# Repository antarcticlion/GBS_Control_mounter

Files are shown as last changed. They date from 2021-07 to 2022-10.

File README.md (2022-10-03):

# GBS_Control_mounter
[GBS-Control](https://github.com/ramapcsx2/gbs-control) Mounting plate for GBS-8200/8220

これはテスト中のプロダクトです。不具合が残っているかもしれません。  

----
# Note for Rev 0.6
外形を調整、クロックジェネレータモジュールを追加。
  
外形  
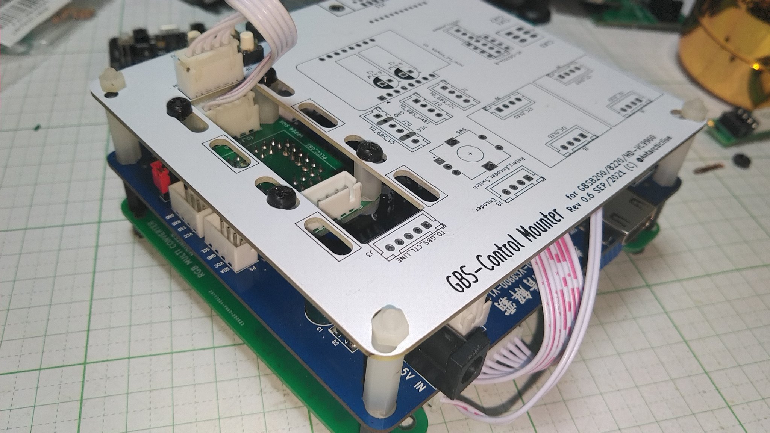
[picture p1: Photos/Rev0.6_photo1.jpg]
Rev06 photo 1
  
  
RGB MULTICONV と一緒にスタックした例  
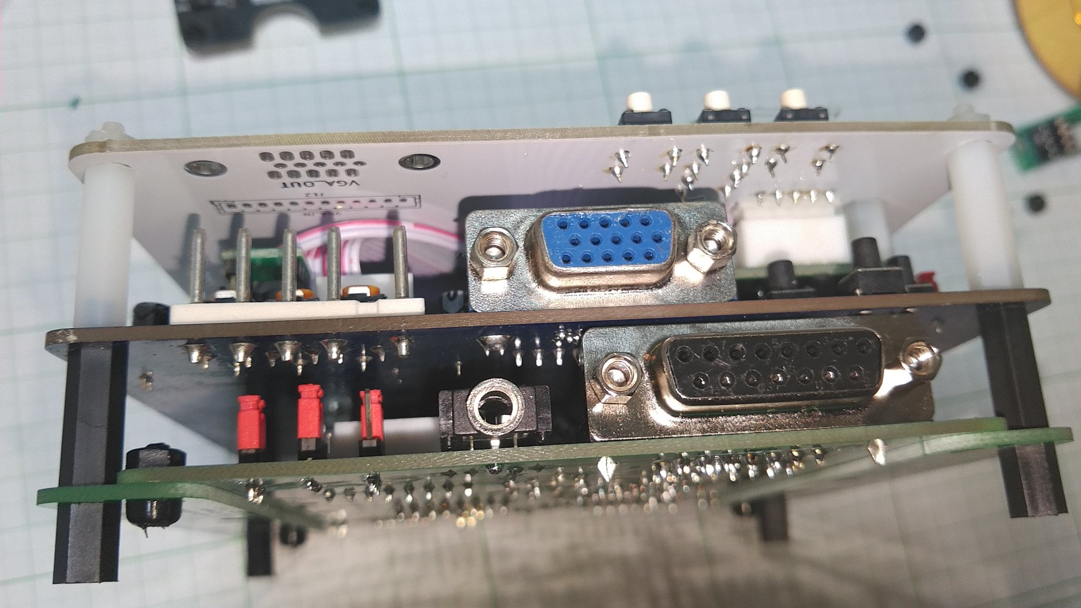
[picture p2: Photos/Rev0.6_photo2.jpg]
Rev06 photo 2
  

クロックジェネレータモジュール(秋月電子通商 AE-Si5351A-Bを使用)
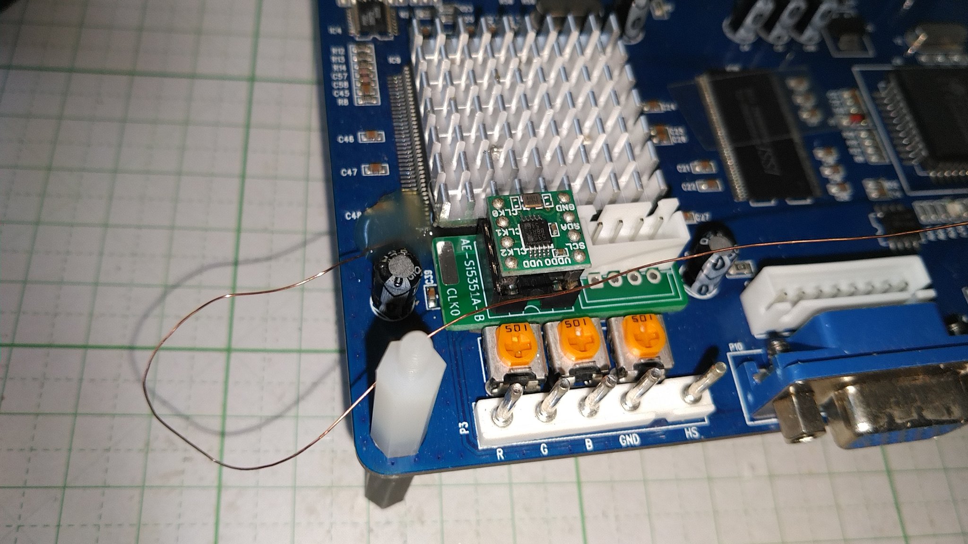
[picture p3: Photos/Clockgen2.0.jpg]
Rev06 photo 3
  

# Note for Rev 0.4
HD-VC9900をサポート

# Note for Rev 0.3
This is a product under test. There may be some bugs left.  
これはテスト中のプロダクトです。不具合が残っているかもしれません。  

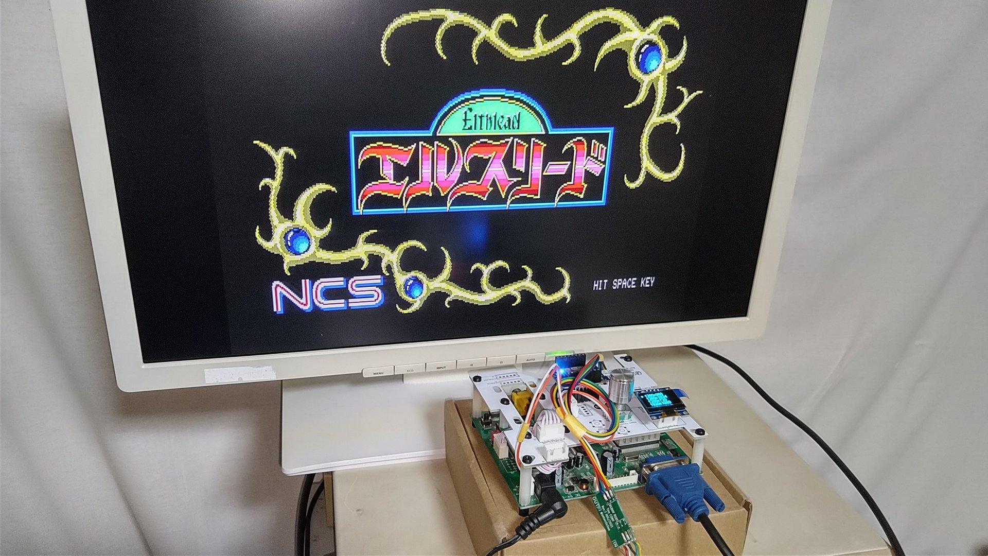
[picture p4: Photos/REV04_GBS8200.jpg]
Rev04 photo 1
  
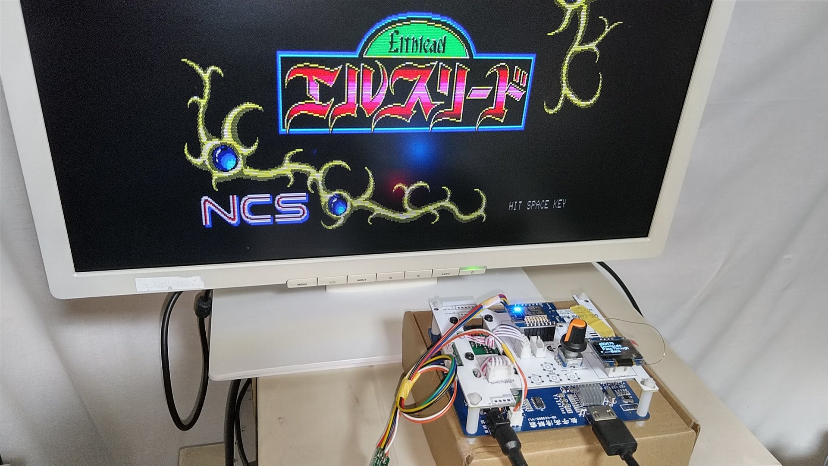
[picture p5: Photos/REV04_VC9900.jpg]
Rev04 photo 2
  
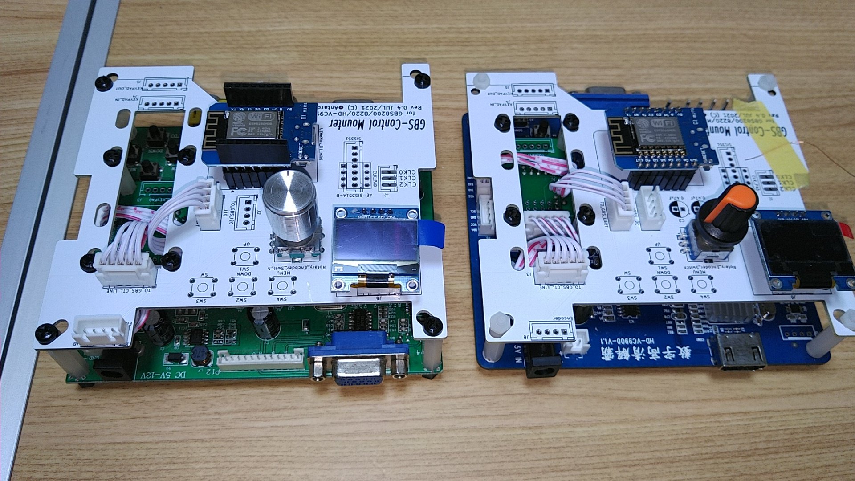
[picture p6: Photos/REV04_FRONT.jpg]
Rev04 photo 1
  
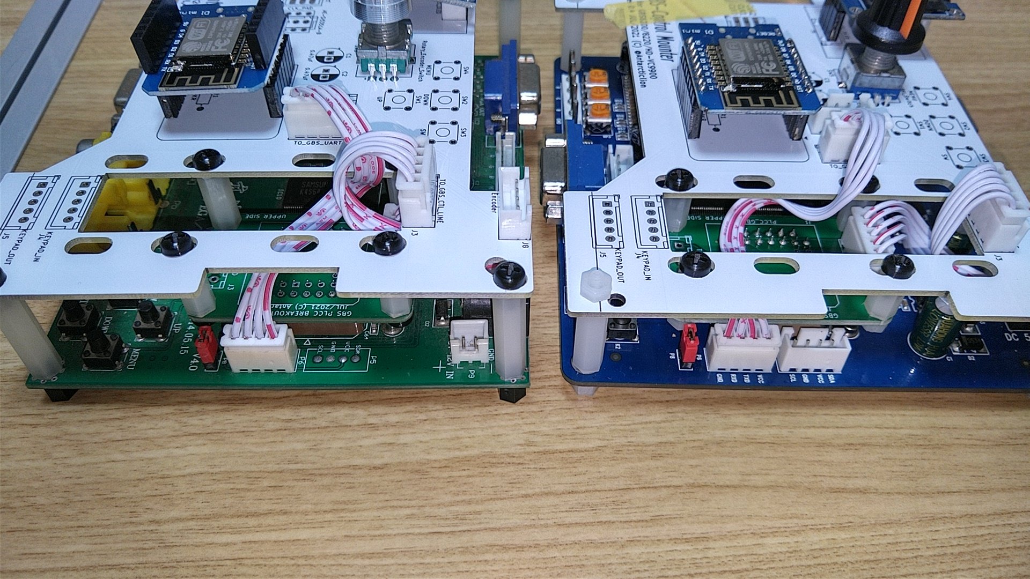
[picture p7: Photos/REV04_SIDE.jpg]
Rev04 photo 2
  
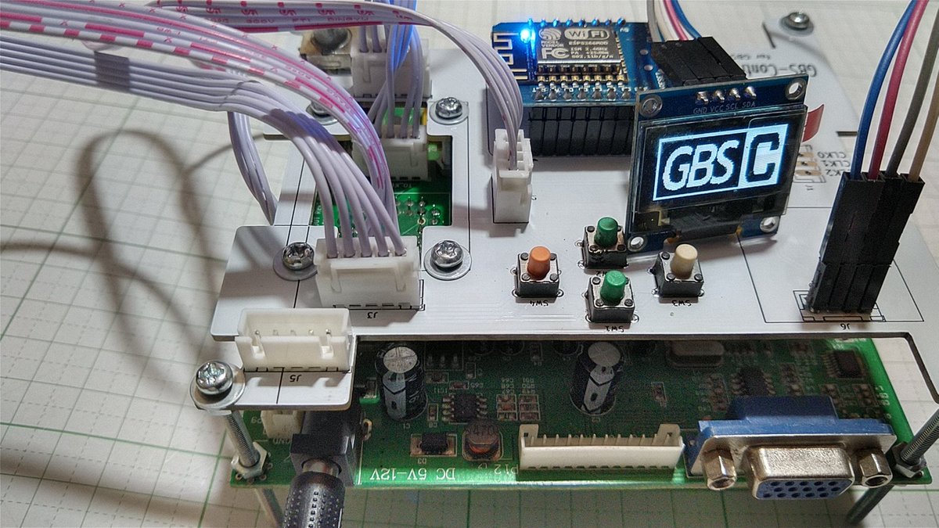
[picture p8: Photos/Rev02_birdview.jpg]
Rev02 photo 1
  
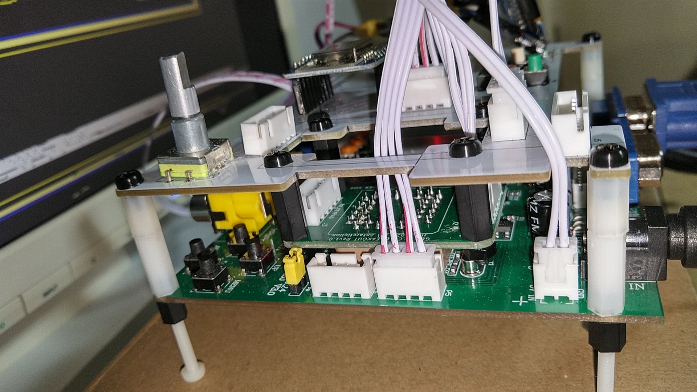
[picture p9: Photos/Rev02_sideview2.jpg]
Rev02 photo 2
  
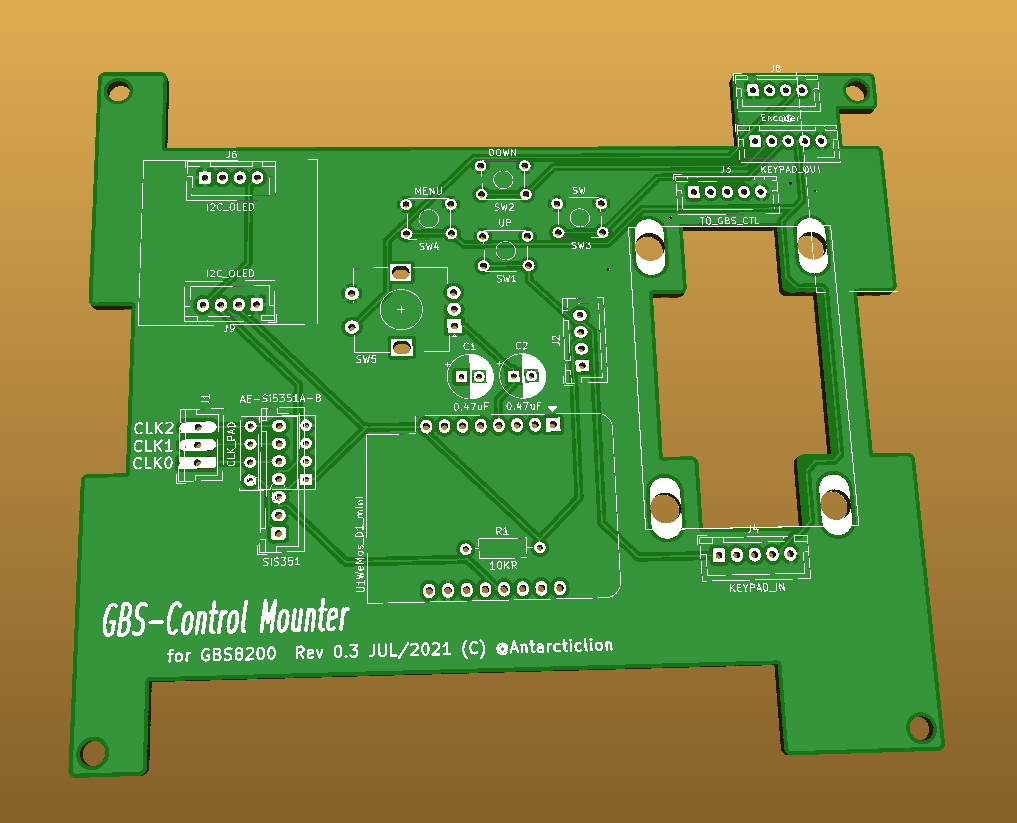
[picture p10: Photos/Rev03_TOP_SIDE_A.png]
Rev03 board 1
  
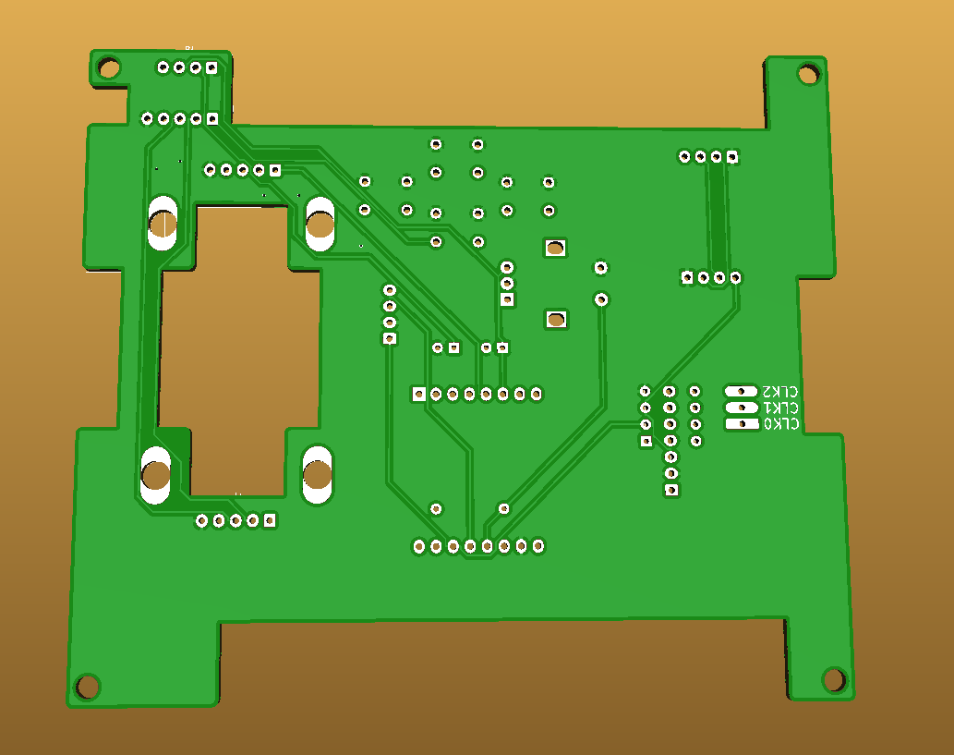
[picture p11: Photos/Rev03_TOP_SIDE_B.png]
  
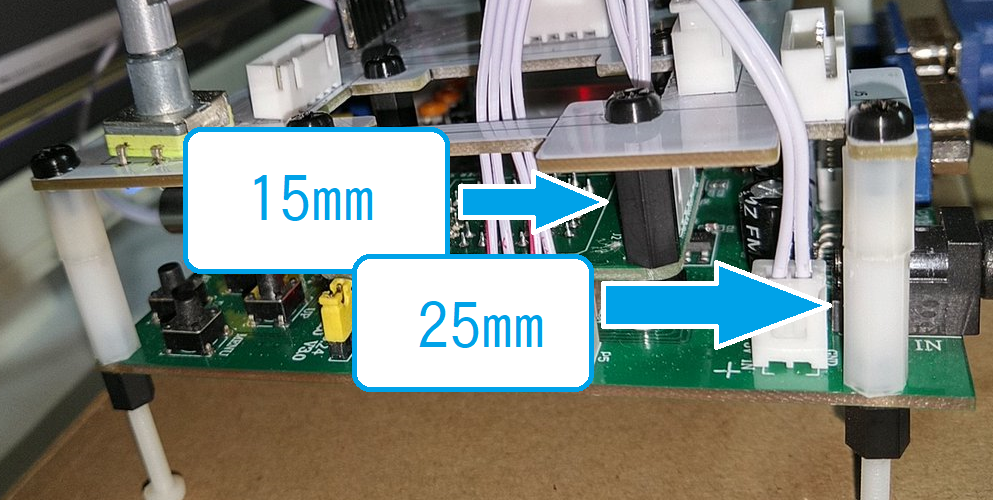
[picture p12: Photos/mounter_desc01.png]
  

# ライセンス

CC BY-SA 4.0とMITライセンスのデュアルライセンスとします。

クリエイティブコモンズ　表示 - 継承 4.0 国際 (CC BY-SA 4.0)

https://creativecommons.org/licenses/by-sa/4.0/  
https://creativecommons.org/licenses/by-sa/4.0/legalcode

Copyright 2019-2020 @antarcticlion

Permission is hereby granted, free of charge, to any person obtaining a copy of this software and associated documentation files (the "Software"), to deal in the Software without restriction, including without limitation the rights to use, copy, modify, merge, publish, distribute, sublicense, and/or sell copies of the Software, and to permit persons to whom the Software is furnished to do so, subject to the following conditions:

The above copyright notice and this permission notice shall be included in all copies or substantial portions of the Software.

THE SOFTWARE IS PROVIDED "AS IS", WITHOUT WARRANTY OF ANY KIND, EXPRESS OR IMPLIED, INCLUDING BUT NOT LIMITED TO THE WARRANTIES OF MERCHANTABILITY, FITNESS FOR A PARTICULAR PURPOSE AND NONINFRINGEMENT. IN NO EVENT SHALL THE AUTHORS OR COPYRIGHT HOLDERS BE LIABLE FOR ANY CLAIM, DAMAGES OR OTHER LIABILITY, WHETHER IN AN ACTION OF CONTRACT, TORT OR OTHERWISE, ARISING FROM, OUT OF OR IN CONNECTION WITH THE SOFTWARE OR THE USE OR OTHER DEALINGS IN THE SOFTWARE.

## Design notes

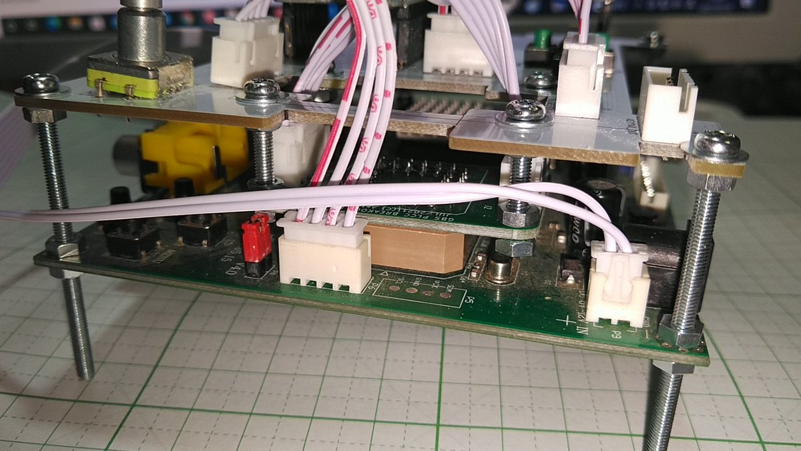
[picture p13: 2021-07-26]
Photos/Rev02_sideview.jpg

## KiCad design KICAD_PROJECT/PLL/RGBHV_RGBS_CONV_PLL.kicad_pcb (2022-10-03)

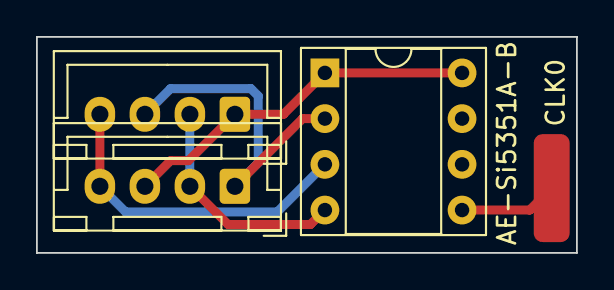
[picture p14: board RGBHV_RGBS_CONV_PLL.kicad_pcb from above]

Board: 2 copper layers, 30.0 x 12.0 mm, 4 parts (0 on the bottom side), 5 nets.

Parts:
J1: I2C OVERLAY; JST_XH_B4B-XH-A_1x04_P2.50mm_Vertical
J4: CLK0; PAD
J5: I2C GBS; JST_XH_B4B-XH-A_1x04_P2.50mm_Vertical
U1: AE-Si5351A-B; DIP-8_W7.62mm_Socket

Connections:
unnamed: J1.1, J5.3, U1.1, U1.8
unnamed: J1.2, J5.2, U1.4
unnamed: J1.3, J5.1, U1.2
unnamed: J1.4, J5.4, U1.3
unnamed: J4.1, U1.5

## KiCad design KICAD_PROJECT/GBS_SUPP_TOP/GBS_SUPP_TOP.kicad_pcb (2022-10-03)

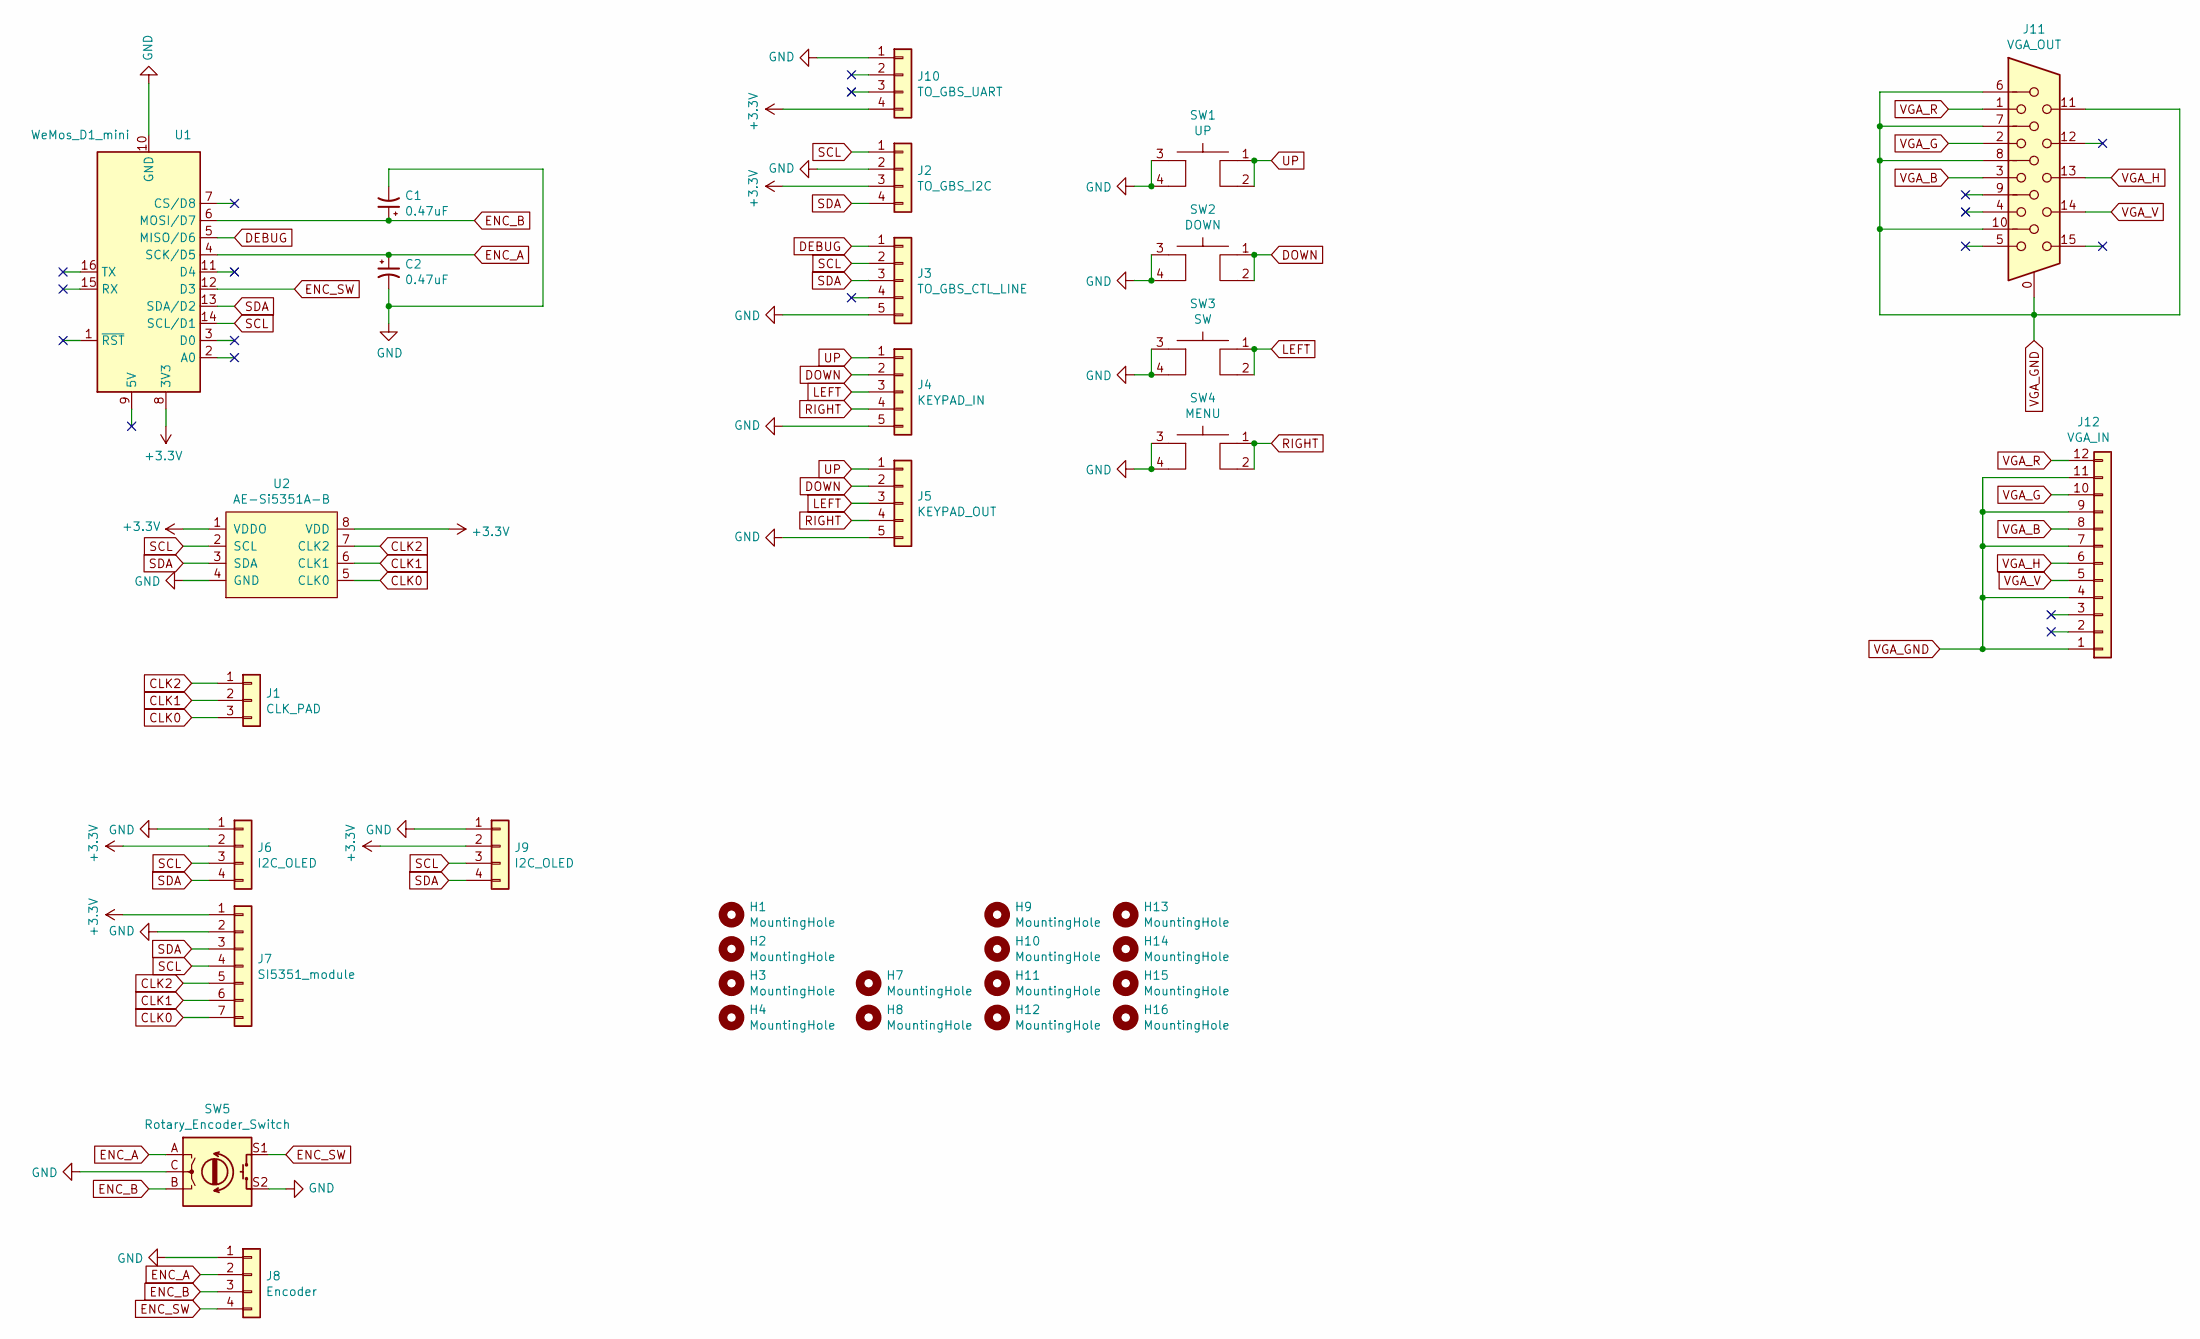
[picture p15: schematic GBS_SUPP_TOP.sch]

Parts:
C1, C2: 0.47uF; CP_Radial_D6.3mm_P2.50mm
H1, H2, H3, H4, H9, H10, H11, H12, H13, H14, H15, H16: MountingHole; MountingHole_4.3mm_M4
H7, H8: MountingHole; MountingHole_3.2mm_M3
J1: CLK_PAD; TerminalBlock_Phoenix_PTSM-0,5-3-2.5-H-THR_1x03_P2.50mm_Hor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
J2: TO_GBS_I2C; JST_XH_B4B-XH-A_1x04_P2.50mm_Vertical
J3: TO_GBS_CTL_LINE; JST_XH_B5B-XH-A_1x05_P2.50mm_Vertical
J4: KEYPAD_IN; JST_XH_B5B-XH-A_1x05_P2.50mm_Vertical
J5: KEYPAD_OUT; JST_XH_B5B-XH-A_1x05_P2.50mm_Vertical
J6, J9: I2C_OLED; JST_XH_B4B-XH-A_1x04_P2.50mm_Vertical
J7: SI5351_module; JST_XH_B7B-XH-A_1x07_P2.50mm_Vertical
J8: Encoder; JST_XH_B4B-XH-A_1x04_P2.50mm_Vertical
J10: TO_GBS_UART; JST_XH_B4B-XH-A_1x04_P2.50mm_Vertical
J11: VGA_OUT; DB_15F-VGA_L
J12: VGA_IN; JST_PH_B12B-PH-K_1x12_P2.00mm_Vertical
SW1: UP; SW_TH_Tactile_Omron_B3F-10xx
SW2: DOWN; SW_TH_Tactile_Omron_B3F-10xx
SW3: SW; SW_TH_Tactile_Omron_B3F-10xx
SW4: MENU; SW_TH_Tactile_Omron_B3F-10xx
SW5: Rotary_Encoder_Switch; RotaryEncoder_Alps_EC12E-Switch_Vertical_H20mm
U1: WeMos_D1_mini; WEMOS_D1_mini_light
U2: AE-Si5351A-B; DIP-8_W7.62mm_Socket

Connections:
+3V3: J2.3, J6.2, J7.1, J9.2, J10.4, U1.8 (3V3), U2.1 (VDDO), U2.8 (VDD); also elsewhere on the board
CLK0: J1.3, J7.7, U2.5 (CLK0)
CLK1: J1.2, J7.6, U2.6 (CLK1)
CLK2: J1.1, J7.5, U2.7 (CLK2)
DEBUG: J3.1, U1.5 (MISO/D6)
DOWN: J4.2, J5.2, SW2.1, SW2.2
ENC_A: C2.1, J8.2, SW5.A, U1.4 (SCK/D5)
ENC_B: C1.1, J8.3, SW5.B, U1.6 (MOSI/D7)
ENC_SW: J8.4, SW5.S1, U1.12 (D3)
GND: C1.2, C2.2, J2.2, J3.5, J4.5, J5.5, J6.1, J7.2, J8.1, J9.1, J10.1, SW1.3, SW1.4, SW2.3, SW2.4, SW3.3, SW3.4, SW4.3, SW4.4, SW5.C, SW5.S2, U1.10 (GND), U2.4 (GND); also elsewhere on the board
LEFT: J4.3, J5.3, SW3.1, SW3.2
RIGHT: J4.4, J5.4, SW4.1, SW4.2
SCL: J2.1, J3.2, J6.3, J7.4, J9.3, U1.14 (SCL/D1), U2.2 (SCL); also elsewhere on the board
SDA: J2.4, J3.3, J6.4, J7.3, J9.4, U1.13 (SDA/D2), U2.3 (SDA); also elsewhere on the board
UP: J4.1, J5.1, SW1.1, SW1.2
VGA_B: J11.3, J12.8
VGA_G: J11.2, J12.10
VGA_GND: J11.0, J11.6, J11.7, J11.8, J11.10, J11.11, J12.1, J12.4, J12.7, J12.9, J12.11
VGA_H: J11.13, J12.6
VGA_R: J11.1, J12.12
VGA_V: J11.14, J12.5

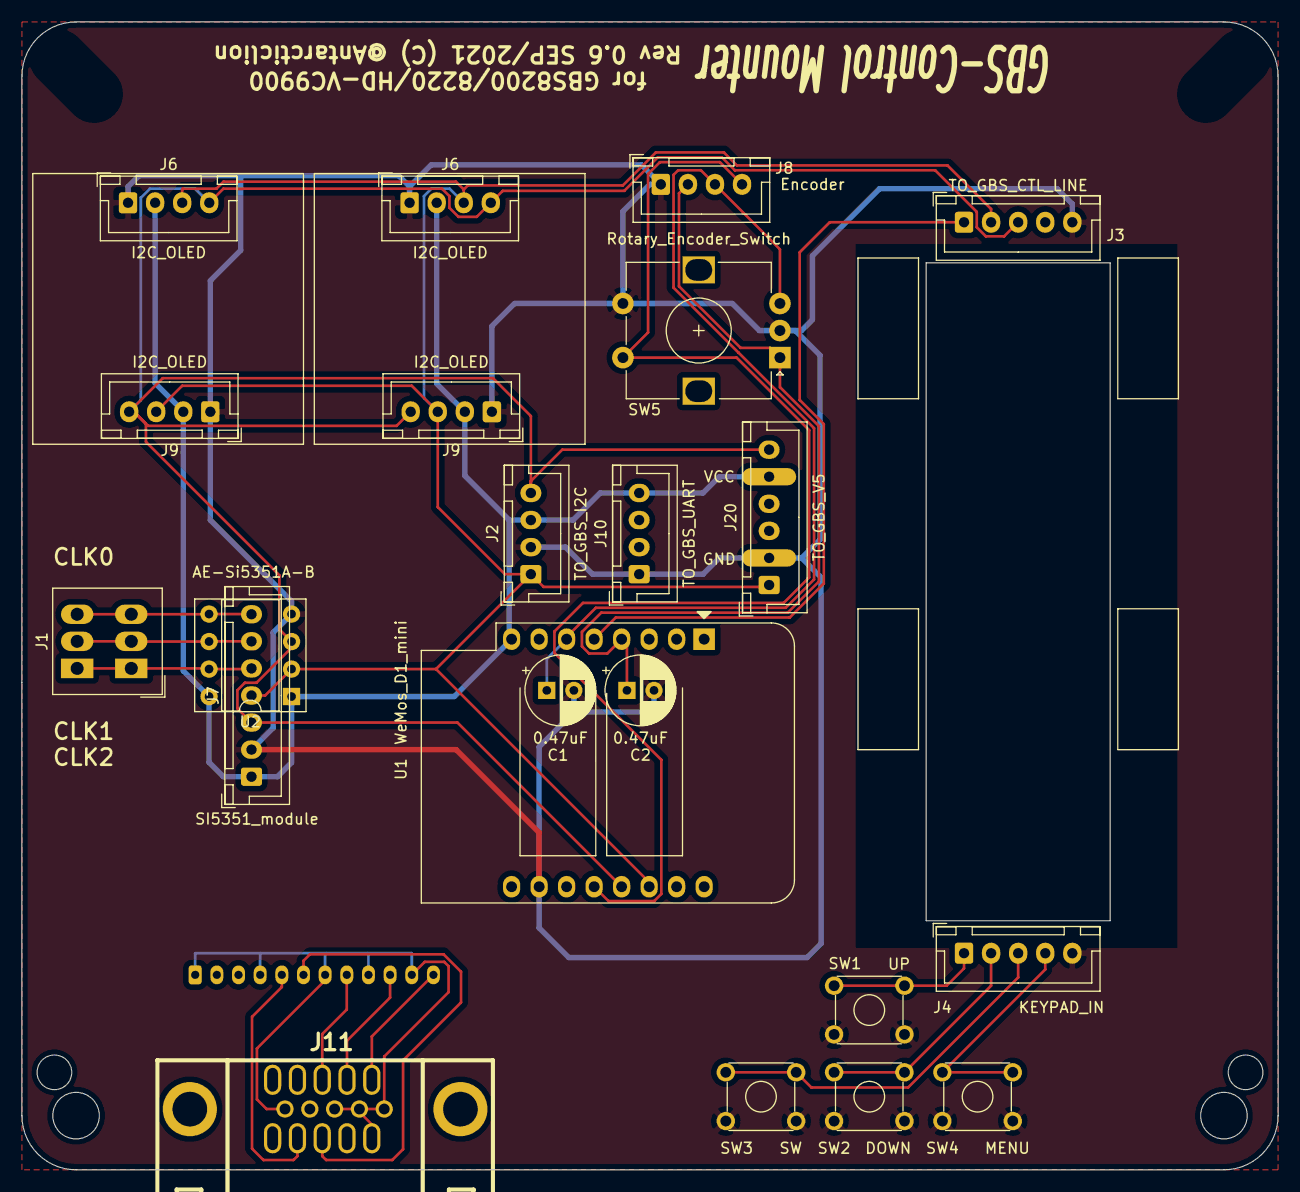
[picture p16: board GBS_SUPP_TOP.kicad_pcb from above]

Board: 2 copper layers, 116.0 x 106.0 mm, 37 parts (1 on the bottom side), 21 nets.

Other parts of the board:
J6#2, J9#2: I2C_OLED; JST_XH_B4B-XH-A_1x04_P2.50mm_Vertical
J20: TO_GBS_V5; JST_XH_B6B-XH-A_1x06_P2.50mm_Vertical

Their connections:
+3V3: J6#2.2, J9#2.2, J20.5; also elsewhere on the board
GND: J6#2.1, J9#2.1, J20.2; also elsewhere on the board
SCL: J6#2.3, J9#2.3, J20.1; also elsewhere on the board
SDA: J6#2.4, J9#2.4, J20.6; also elsewhere on the board

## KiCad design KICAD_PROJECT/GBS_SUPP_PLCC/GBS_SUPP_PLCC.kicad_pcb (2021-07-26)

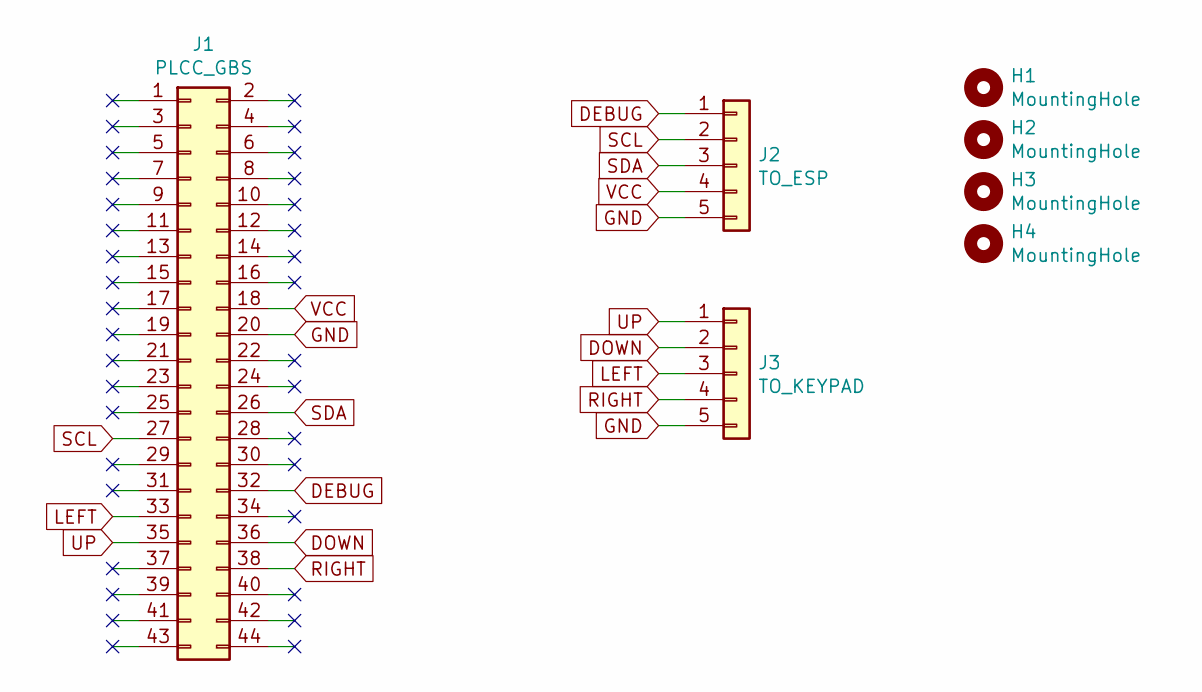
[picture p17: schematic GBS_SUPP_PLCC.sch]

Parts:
H1, H2, H3, H4: MountingHole; MountingHole_3.2mm_M3
J1: PLCC_GBS; PLCC-44_THT-Socket
J2: TO_ESP; JST_XH_B5B-XH-A_1x05_P2.50mm_Vertical
J3: TO_KEYPAD; JST_XH_B5B-XH-A_1x05_P2.50mm_Vertical

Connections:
DEBUG: J1.32, J2.1
DOWN: J1.36, J3.2
GND: J1.20, J2.5, J3.5
LEFT: J1.33, J3.3
RIGHT: J1.38, J3.4
SCL: J1.27, J2.2
SDA: J1.26, J2.3
UP: J1.35, J3.1
VCC: J1.18, J2.4

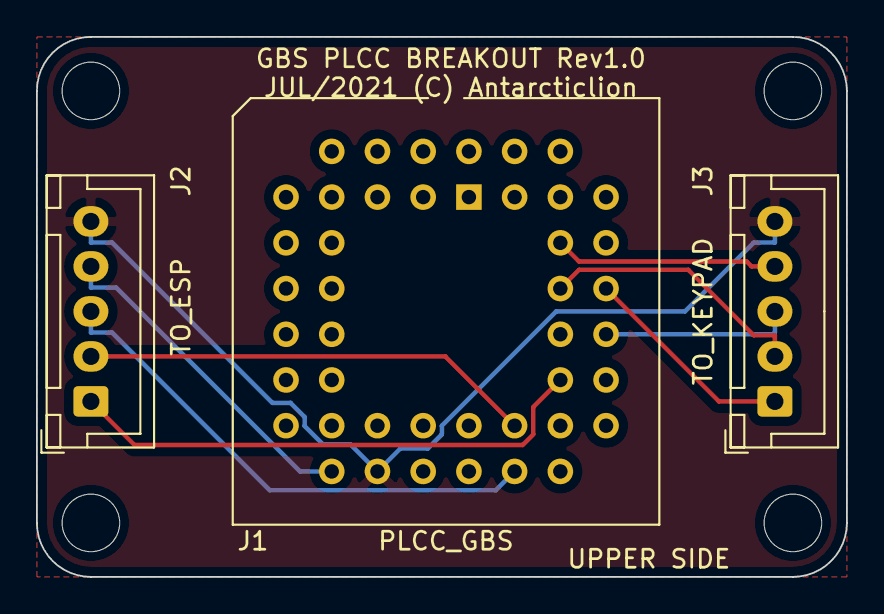
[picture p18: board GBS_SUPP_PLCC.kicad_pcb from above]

Board: 2 copper layers, 45.0 x 30.0 mm, 7 parts (0 on the bottom side), 9 nets.

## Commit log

2021-07-26 Initial Upload
    [GBS_SUPP_PLCC.kicad_pcb, GBS_SUPP_PLCC.sch, GBS_SUPP_TOP.kicad_pcb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]
2021-08-03 Rev0.3A
    Fix PLCC Board mounting hole problem.
    [GBS_SUPP_TOP.kicad_pcb]
2021-08-18 Rev 0.4
    Support HD-VC9900
    [GBS_SUPP_TOP.kicad_pcb, GBS_SUPP_TOP.sch]
2022-10-03 Rev 0.6
    [GBS_SUPP_TOP.kicad_pcb, GBS_SUPP_TOP.sch]
2022-10-03 Clockgen module Rev2.0
    [RGBHV_RGBS_CONV_PLL.kicad_pcb, RGBHV_RGBS_CONV_PLL.sch]

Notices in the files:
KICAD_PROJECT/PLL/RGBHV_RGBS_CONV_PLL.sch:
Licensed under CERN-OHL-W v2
